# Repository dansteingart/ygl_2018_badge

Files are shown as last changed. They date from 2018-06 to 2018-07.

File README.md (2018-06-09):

## Overview

This is the sensor and code layout for the YGL 2018 Badge. 

The badge measures
- Ambient Temperature (via a DHT22 and a MLX90614)
- Focussed Temperature (via a MLX90614)
- Ambient Humidity (via a DHT22)

The badge also allows the wearer to indicate comfort level
- Red (hot)
- Blue (cold)
- Green (comfortable)

The badge attempts to connect to preprogammed wifi SSID's, and if it is connect it reports the ambient conditions once a minute and the user comfort on signaling.

## Board Schematics

The board can be edited in [Eagle](https://www.autodesk.com/products/eagle/free-download) 

## Code

The code for this is meant to be uploaded through the [build.particle.io](https://build.particle.io), but can also be compiled and sent remotely.

## How To Measure Things
This [document](https://docs.google.com/document/d/e/2PACX-1vTs8eymRHai5XaTd2wvhhjKwmNey0X5QBFbXBKoaI53rYneKwUvtwl-gOKRnENuz1WqiknrLIXWhSsD/pub)([PDF](https://docs.google.com/document/d/11KgSaUlBZMfQc9rQ66gh0Wr3Of6fnvB99Y8Q6VOIqZM/export?format=pdf)) describes how and why this all works, and what we're trying to do.

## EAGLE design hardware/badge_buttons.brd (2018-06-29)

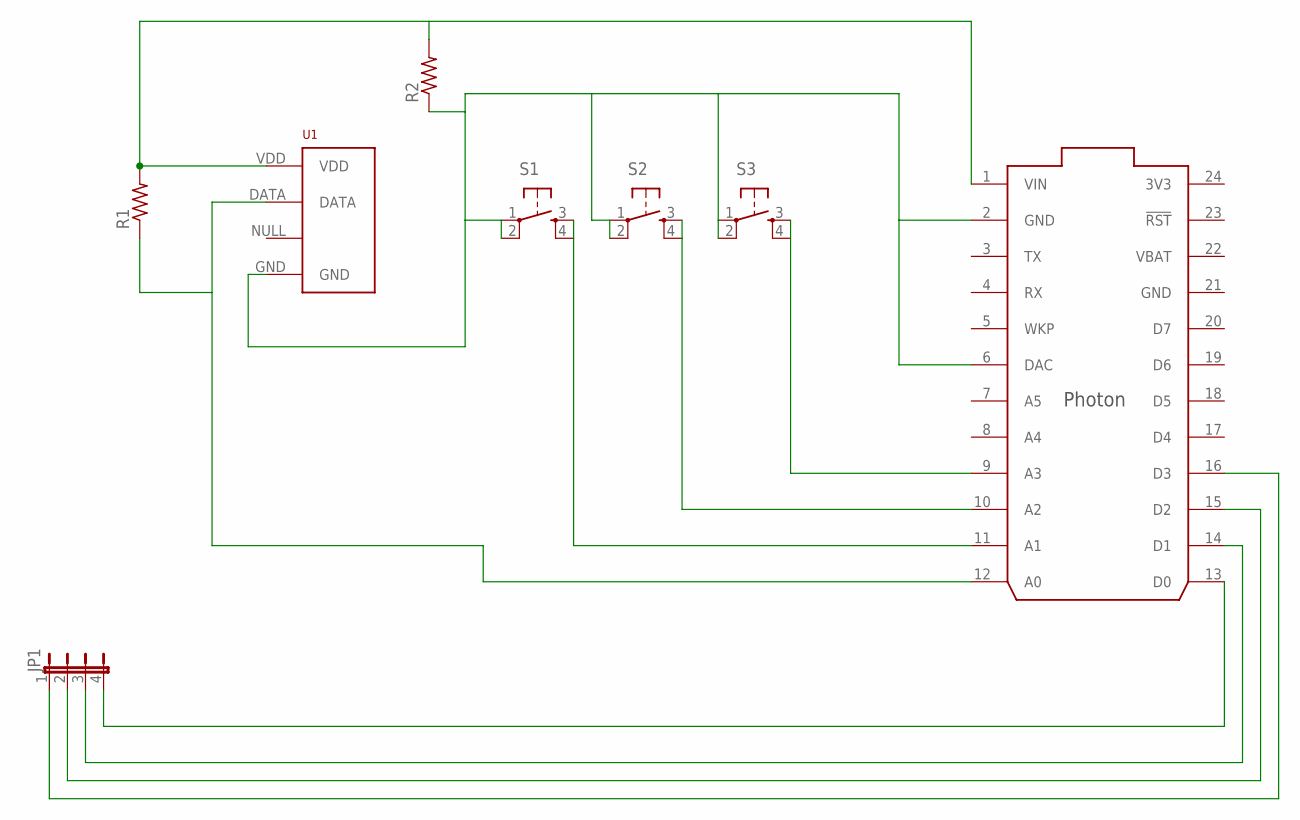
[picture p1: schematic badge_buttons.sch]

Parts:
JP1: JP4E; JP4
R1, R2: R-US_0204/7; 0204/7
S1, S2, S3: TAC_SWITCHPTH; TACTILE-PTH
U1: RHT03_DHT-22_AM2302; RHT03_DHT-22
U$1: PHOTON_WITH_HEADERS; PHOTON

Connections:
3V3: U$1.24 (3V3)
GND: U$1.21 (GND)
unnamed: S3.3, S3.4, U$1.9 (A3)
unnamed: S2.3, S2.4, U$1.10 (A2)
unnamed: S1.3, S1.4, U$1.11 (A1)
unnamed: R2.1, S1.1, S1.2, S2.1, S2.2, S3.1, S3.2, U1.GND, U$1.2 (GND), U$1.6 (DAC)
unnamed: R1.2, R2.2, U1.VDD, U$1.1 (VIN)
unnamed: R1.1, U1.DATA, U$1.12 (A0)
unnamed: JP1.4, U$1.13 (D0)
unnamed: JP1.3, U$1.14 (D1)
unnamed: JP1.2, U$1.15 (D2)
unnamed: JP1.1, U$1.16 (D3)
VBAT: U$1.22 (VBAT)

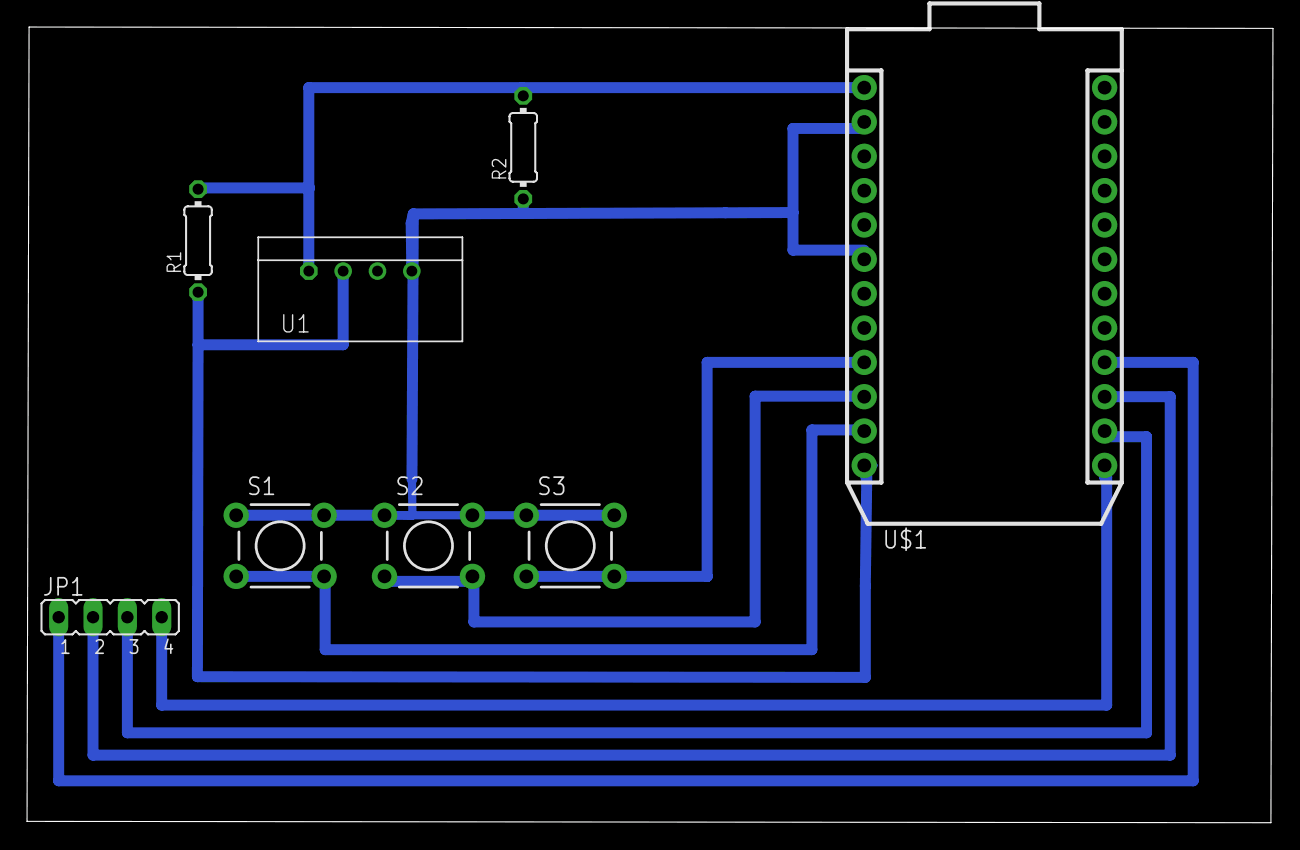
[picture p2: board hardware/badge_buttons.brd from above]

Board: 2 copper layers, 92.2 x 58.9 mm, 8 parts (0 on the bottom side), 10 nets.

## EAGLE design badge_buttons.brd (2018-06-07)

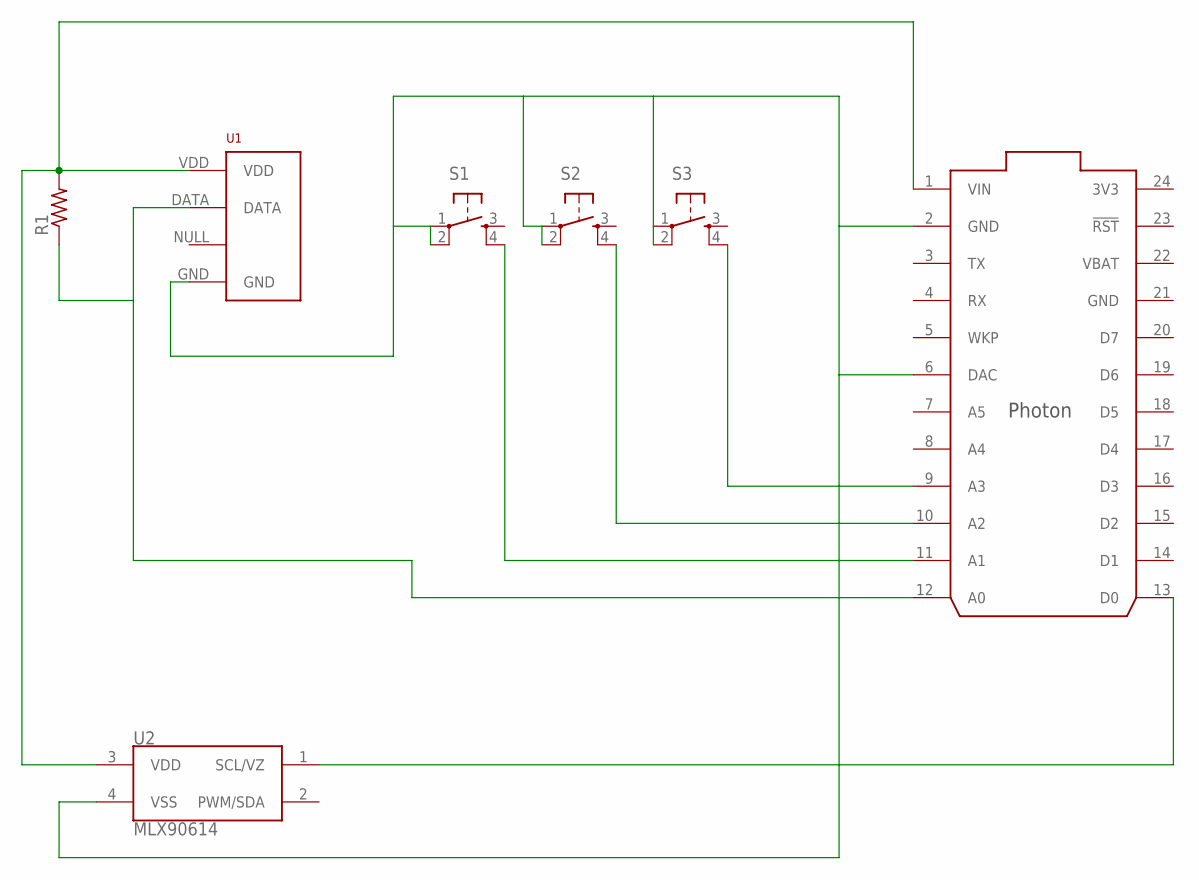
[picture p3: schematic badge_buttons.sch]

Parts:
R1: R-US_0204/7; 0204/7
S1, S2, S3: TAC_SWITCHPTH; TACTILE-PTH
U1: RHT03_DHT-22_AM2302; RHT03_DHT-22
U2: MLX90614; TO-39
U$1: PHOTON_WITH_HEADERS; PHOTON

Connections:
3V3: U$1.24 (3V3)
GND: U$1.21 (GND)
unnamed: S3.4, U$1.9 (A3)
unnamed: S2.4, U$1.10 (A2)
unnamed: S1.4, U$1.11 (A1)
unnamed: S1.1, S1.2, S2.1, S2.2, S3.1, S3.2, U1.GND, U2.4 (VSS), U$1.2 (GND), U$1.6 (DAC)
unnamed: R1.2, U1.VDD, U2.3 (VDD), U$1.1 (VIN)
unnamed: R1.1, U1.DATA, U$1.12 (A0)
unnamed: U2.1 (SCL/VZ), U$1.13 (D0)
VBAT: U$1.22 (VBAT)

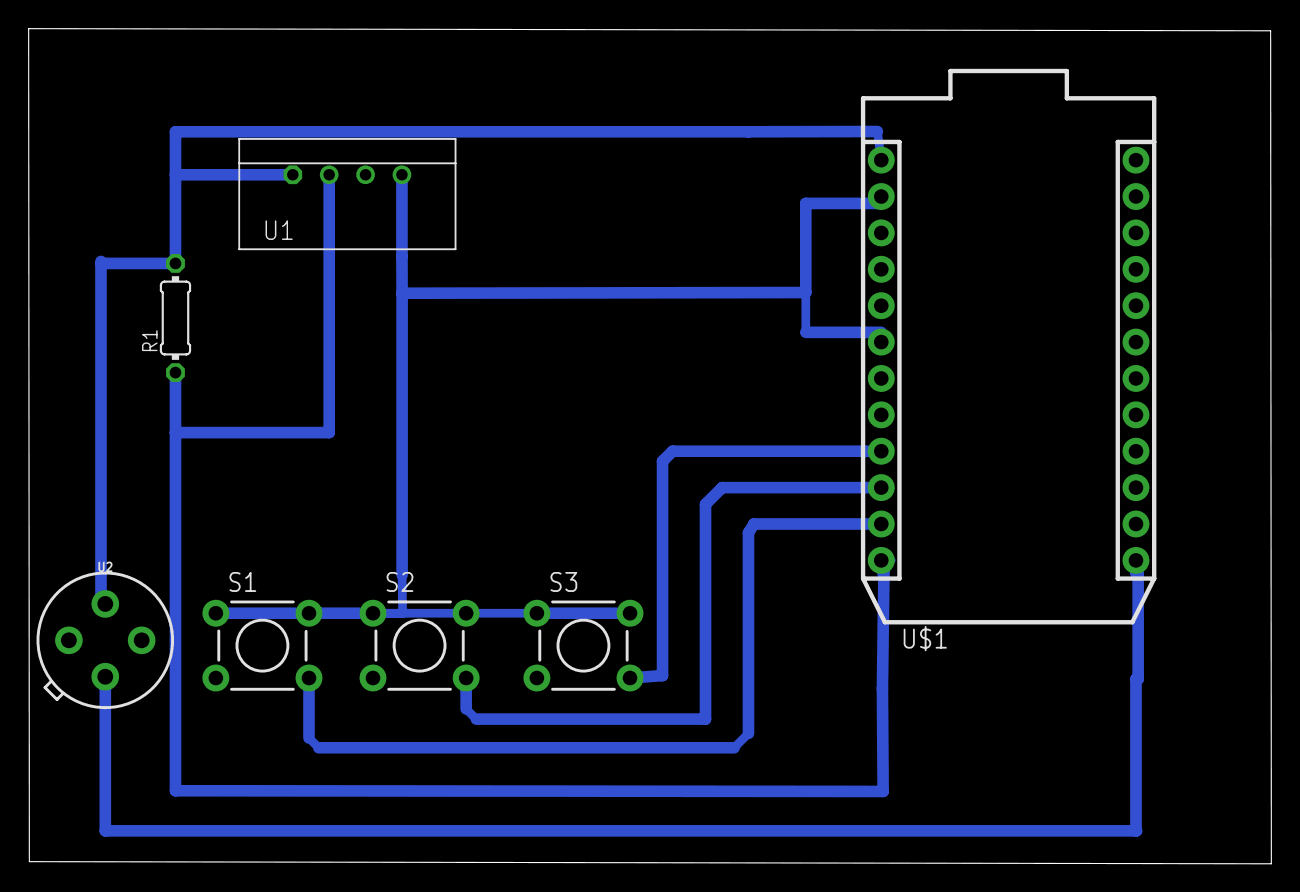
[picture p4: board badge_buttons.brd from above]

Board: 2 copper layers, 86.8 x 58.3 mm, 7 parts (0 on the bottom side), 7 nets.

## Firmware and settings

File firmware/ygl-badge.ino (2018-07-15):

// Base Code for YGL Badge
// Author: Dan Steingart
// Date Started: 2018-03-25
// Date Last Modified: 2018-07-02

/*


This code
  - pings an attached DHT22 sensor for T/RH,
  - pings an attached MLX90614 sensor for focussed and ambient temperature
  - can detect whether or not it is in the badge and change sampling rate as a function thereof (for hacking)
  - pings the powersield for battery voltage and SOC
  - allows for comfort signaling via three buttons
  - samples for A4 for voltage divider demo
  - send JSON formatted code is sent via the YGL event

  ** as of 2018-06-08 there is noise in the A4 signal on a breadboard, likely due to a lack of pull up resistors.
  *** Because we are awesome we just use a rolling_mean on the data set to pretend it's not there.

*/

PRODUCT_ID(7743);
PRODUCT_VERSION(1);


#include "DHT.h"
#define DHTPINA A0  // Digital pin D2
#define DHTTYPE DHT22
#include "math.h"

#include "Adafruit_MLX90614.h"
#include "PowerShield.h"


DHT dhta(DHTPINA, DHTTYPE);

double calibration_factor = 0.64;
// USER INPUT ** END **

double h1;    // humidity
double t1;    // temperature c
double tb;
double ta;

Adafruit_MLX90614 mlx = Adafruit_MLX90614();
PowerShield batteryMonitor;


char publishString[200]; //a place holer for the publish string
char triggerString[200]; //a place holer for the publish string

int waiter = 10; //in ms
int samps = 100; //ticks before timed send (waiter*samps = ms )
int push_waiter = 2000;
long push_counter = 0;
long wait_counter = 0;
void setup() //run this loop just once upon start, or upon reset
{
  //This will send back the big data string
  Particle.variable("YGL",triggerString);
  //We'll use these to send the digital state

  //set analog pins to input mode
  pinMode(A3, INPUT);
  pinMode(A1, INPUT);
  pinMode(A2, INPUT);
  pinMode(A4, INPUT);
  pinMode(A6, INPUT);

  pinMode(D2, OUTPUT); //led
  pinMode(D3, OUTPUT); //led
  pinMode(D7, OUTPUT); //led


  digitalWrite(D2,LOW);
  digitalWrite(D3,HIGH);

  dhta.begin();

  mlx.begin();
  batteryMonitor.begin();
  RGB.control(true);
  // RGB.color(255,255,255);
  RGB.color(0,0,0);
  RGB.brightness(0);


}

float calibrated_value(float input, float factor) {
    return input + factor;
}

void loop() //repeat this loop forever
{

    //badge ADCS
    int an1 = analogRead(3); //Red button
    int an2 = analogRead(1); //Blue button
    int an0 = analogRead(2); //Green button
    int an6 = analogRead(6); //badge detect if shorted to gnd.

    //detect badge yes/no
    bool badge = false;
    if (an6 < 20) badge = true;
    else badge = false;

    //if we're in the badge, send less to power save
    if (badge) samps = 500; // 500 to avoid DHT heating
    else samps = 100;

    if ((an0 < 10  || an1 < 10 || an2 < 10 ) && millis()-push_counter > push_waiter)
    {

            push_counter = millis();
            Particle.publish("YGL",triggerString);
            RGB.control(true);

            h1 = dhta.readHumidity();
            t1 = dhta.readTemperature(false);
            t1 = calibrated_value(t1, calibration_factor);

            double amb = mlx.readAmbientTempC();
            double finger = mlx.readObjectTempC();

            float a4 = 0;

            wait_counter = 0;


            int state = 42;

            if  (an0 < 10)
            {
                RGB.color(0,  255,  0);
                state = 1;
                //sprintf(triggerString,"{\"type\":\"trigger\",\"state\":\"good\"}");

            }
            else if (an1 < 10)
            {
                RGB.color(255,   0,  0);
                //sprintf(triggerString,"{\"type\":\"trigger\",\"state\":\"hot\"}");
                state = 0;
            }
            else if (an2 < 10)
            {
                RGB.color(   0, 0,  255);
                //sprintf(triggerString,"{\"type\":\"trigger\",\"state\":\"cold\"}");
                state = 2;
            }

            sprintf(publishString,"{\"type\":\"trigger\",\"T_DHT22\": %f,\"H_DHT22\": %f,\"T_amb_MLX\": %f,\"T_sen_MLX\": %f,\"a4\":%f,\"state\":%d}",t1,h1,amb,finger,a4,state);
            Particle.publish("YGL",publishString);
            RGB.brightness(255);
            delay(500);
            // RGB.color(255,255,255);
            // RGB.brightness(255);
            //RGB.color(0,0,0);
            RGB.brightness(10);

            //RGB.control(false);
    }

    delay(waiter);

    wait_counter += 1;
    if (wait_counter > samps)
    {
        h1 = 0;
        t1 = 0;
        double amb = 0;
        double finger = 0;

        if (badge)
        {
          h1 = dhta.readHumidity();
          t1 = dhta.readTemperature(false);
          t1 = calibrated_value(t1, calibration_factor);
          amb = mlx.readAmbientTempC();
          finger = mlx.readObjectTempC();
        }

        float a4 = 0;
        int lim = 1;
        for (int i = 0; i < lim;i++) a4 = a4 + analogRead(A4);
        a4 = a4/lim;

        wait_counter = 0;
        sprintf(publishString,"{\"type\":\"timer\",\"T_DHT22\": %f,\"H_DHT22\": %f,\"T_amb_MLX\": %f,\"T_sen_MLX\": %f,\"a4\":%f}",t1,h1,amb,finger,a4);
        Particle.publish("YGL",publishString);
        digitalWrite(7,1);
        delay(50);
        digitalWrite(7,0);


    }

}

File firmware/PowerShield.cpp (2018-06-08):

//
// PowerShield.cpp
// Library for the Particle Power Shield
// Based on original library published by Luca Dentella (http://www.lucadentella.it)
// Modified by Mohit Bhoite @ Particle Industries, Inc. July 2015
// Power Shield Documentation: http://docs.particle.io/photon/shields/#power-shield
// MAX17043 datasheet: http://datasheets.maximintegrated.com/en/ds/MAX17043-MAX17044.pdf
//

/*
         -----[    ]-----
        -|VIN        3V3|-
        -|GND        RST|-
        -|TX        VBAT|-
        -|RX         GND|-
        -|WKP         D7|-
        -|DAC         D6|-
        -|A5          D5|-
        -|A4          D4|-
        -|A3          D3|- ALERT interrupt from MAX17043 (optional solder bridge)
        -|A2          D2|-
        -|A1          D1|- SCL |- MAX17043 connected to the I2C channel with address 0x36
        -|A0          D0|- SDA |
          \____________/

*/


#include "PowerShield.h"

PowerShield::PowerShield()
{

}

bool PowerShield::begin()
{
	Wire.begin();
	return 1;
}

// Read and return the cell voltage
float PowerShield::getVCell() {

	byte MSB = 0;
	byte LSB = 0;

	readRegister(VCELL_REGISTER, MSB, LSB);
	int value = (MSB << 4) | (LSB >> 4);
	return map(value, 0x000, 0xFFF, 0, 50000) / 10000.0;
	//return value * 0.00125;
}

// Read and return the state of charge of the cell
float PowerShield::getSoC() {

	byte MSB = 0;
	byte LSB = 0;

	readRegister(SOC_REGISTER, MSB, LSB);
	float decimal = LSB / 256.0;
	return MSB + decimal;
}

// Return the version number of the chip
int PowerShield::getVersion() {

	byte MSB = 0;
	byte LSB = 0;

	readRegister(VERSION_REGISTER, MSB, LSB);
	return (MSB << 8) | LSB;
}

byte PowerShield::getCompensateValue() {

	byte MSB = 0;
	byte LSB = 0;

	readConfigRegister(MSB, LSB);
	return MSB;
}

byte PowerShield::getAlertThreshold() {

	byte MSB = 0;
	byte LSB = 0;

	readConfigRegister(MSB, LSB);
	return 32 - (LSB & 0x1F);
}

void PowerShield::setAlertThreshold(byte threshold) {

	byte MSB = 0;
	byte LSB = 0;

	readConfigRegister(MSB, LSB);
	if(threshold > 32) threshold = 32;
	threshold = 32 - threshold;

	writeRegister(CONFIG_REGISTER, MSB, (LSB & 0xE0) | threshold);
}

// Check if alert interrupt was generated
bool PowerShield::getAlert() {

	byte MSB = 0;
	byte LSB = 0;

	readConfigRegister(MSB, LSB);
	return LSB & 0x20;
}

void PowerShield::clearAlert() {

	byte MSB = 0;
	byte LSB = 0;

	readConfigRegister(MSB, LSB);
}

void PowerShield::reset() {

	writeRegister(COMMAND_REGISTER, 0x00, 0x54);
}

void PowerShield::quickStart() {

	writeRegister(MODE_REGISTER, 0x40, 0x00);
}


void PowerShield::readConfigRegister(byte &MSB, byte &LSB) {

	readRegister(CONFIG_REGISTER, MSB, LSB);
}

void PowerShield::readRegister(byte startAddress, byte &MSB, byte &LSB) {

	Wire.beginTransmission(MAX17043_ADDRESS);
	Wire.write(startAddress);
	Wire.endTransmission();

	Wire.requestFrom(MAX17043_ADDRESS, 2);
	MSB = Wire.read();
	LSB = Wire.read();
}

void PowerShield::writeRegister(byte address, byte MSB, byte LSB) {

	Wire.beginTransmission(MAX17043_ADDRESS);
	Wire.write(address);
	Wire.write(MSB);
	Wire.write(LSB);
	Wire.endTransmission();
}

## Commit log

2018-05-30 first files
    [badge_buttons.brd, badge_buttons.sch]
2018-06-07 clean up lines, add sensor loop
    [badge_buttons.brd, badge_buttons.sch]
2018-06-07 fatten traces
    [badge_buttons.brd]
2018-06-07 MLX succesfully added to code
    [badge_buttons.brd, badge_buttons.sch]
2018-06-07 refactor directory/finish wiring
    [badge_buttons.brd, badge_buttons.sch]
2018-06-08 add powershield SOC/Cell Potential
2018-06-08 sensible button order
2018-06-28 last add
    [badge_buttons.brd]
2018-06-28 pusher T
    [badge_buttons.brd, badge_buttons.sch]
2018-06-28 Wingoneer Change
    [badge_buttons.brd, badge_buttons.sch]
2018-06-28 fattened pads
    [badge_buttons.brd]
2018-06-28 othermill layout for 1x2 cut
2018-06-29 power hogging
    [badge_buttons.brd, badge_buttons.sch]

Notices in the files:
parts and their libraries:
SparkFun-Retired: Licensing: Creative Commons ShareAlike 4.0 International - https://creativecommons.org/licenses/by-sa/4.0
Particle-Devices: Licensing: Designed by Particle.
